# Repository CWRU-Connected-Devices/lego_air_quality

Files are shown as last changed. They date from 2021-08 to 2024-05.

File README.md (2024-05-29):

# Assembly Process

## Wire Preparation
- Cut all wires to length using a piece of cardboard as a reference length
- Stripped and twisted wires    
- Pre-soldered wires 

## Soldering wires to peripherals
- Soldered LEDs
- Soldered Sensors
- Soldered Neopixel LED bars
- Stripped and soldered the fans  

## Peripheral board Assembly
- Soldered male headers onto Peripheral boards
- Soldered peripherals to each Peripheral board
- Cleaned Peripheral boards
- Tested each Peripheral board using a test Pico with female headers soldered on 

## Pico Assembly
- Soldered the rest of the Peripheral boards to Picos
- Flashed using Thonny
- Tested each kit
	- Make sure the LED blinks two times and then lights up    
	- Make sure the Neopixel bar works (will cycle a rainbow pattern)
	- Make sure the calibration process finishes - Neopixel bar turns blue and then turns red
	- Make sure the change in luminance on the sensor results in a corresponding change on the Neopixel bar indicator

## Glueing
- ### LED and Sensor Bricks
	- Hot glue first on brick
	- Place peripheral on layer of glue
	- Finish by covering the rest of peripheral in glue
	- Strain relieved the wires with a drop of hot glue
	- Attached other half of brick by adding superglue to the rim and pressing them together
    
- ### Casing
	- Superglue the bottom to the top of the case
	- Placed Pico/Peripheral board assembly inside case
	- A drop of hot glue under the Pico to hold it in place
	- Final test  
      
## Finishing touches
- Pull the wires through the strain relief bars on the case
- Tie the wires with cable ties

# Uploading code onto pico

1. Hold the BOOTSEL button on the pico and plug it into the computer    
2. Pico folder shows up with two files currently inside
   
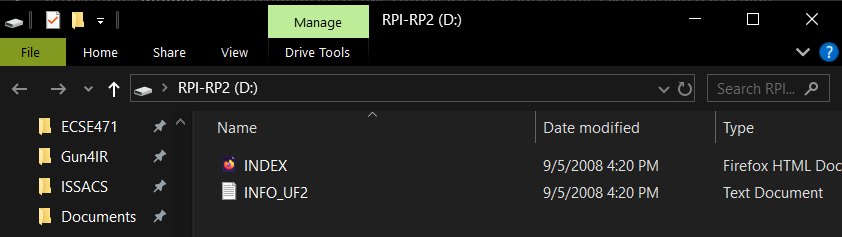
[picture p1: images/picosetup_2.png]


3. Drag the UF2 file into the pico folder
    
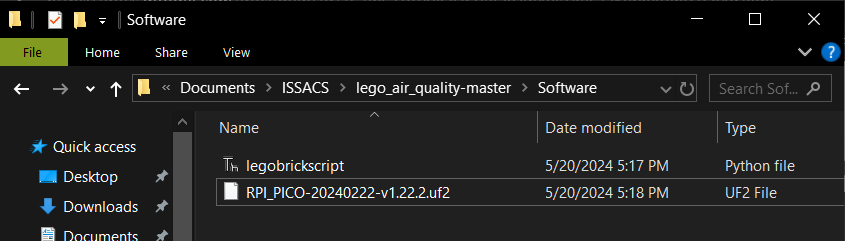
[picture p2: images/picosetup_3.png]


4. Pico folder now closes
5. Open Thonny and at the bottom right corner select the COM port 
   
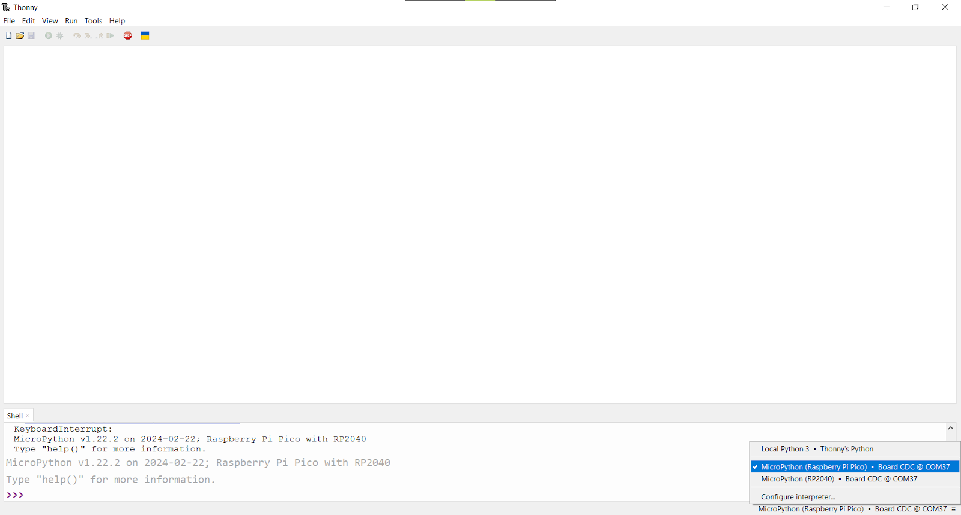
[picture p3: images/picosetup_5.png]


6. Open legobrickscript.py
7. Go to File > Save Copy 
8. When asked where to save, select the Raspberry Pi Pico

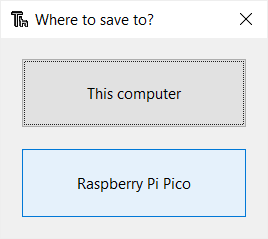
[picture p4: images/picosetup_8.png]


9. Rename the file as main.py and press OK
   
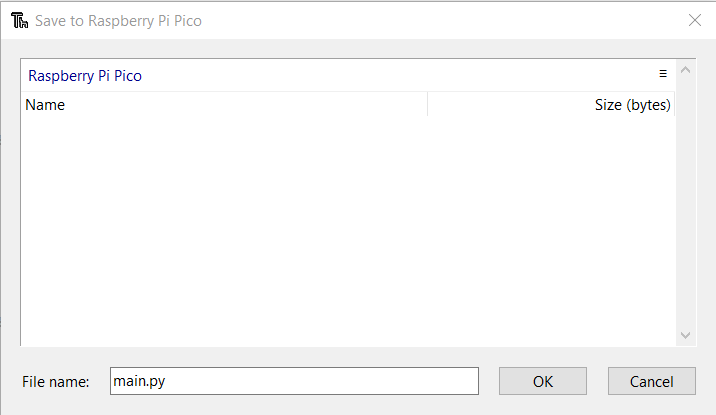
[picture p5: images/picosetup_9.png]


10. Ctrl-D to boot the Pico
    
# Setup

- Used Studio 2.0
   - Download Link https://www.bricklink.com/v3/studio/download.page
    
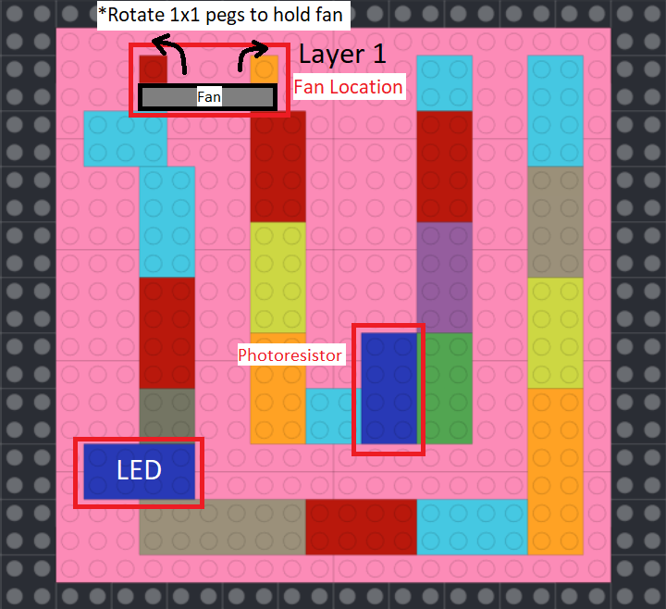
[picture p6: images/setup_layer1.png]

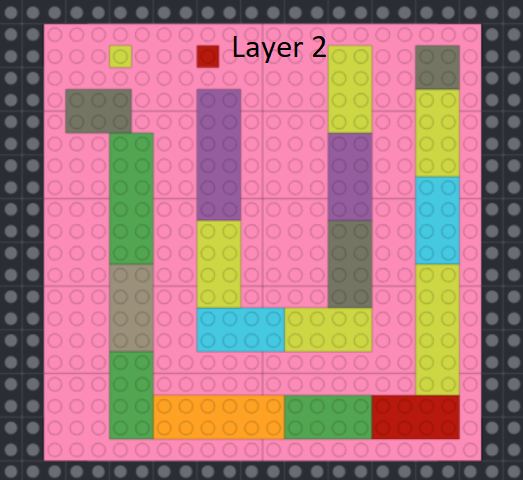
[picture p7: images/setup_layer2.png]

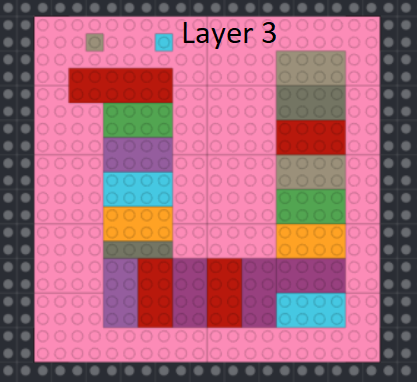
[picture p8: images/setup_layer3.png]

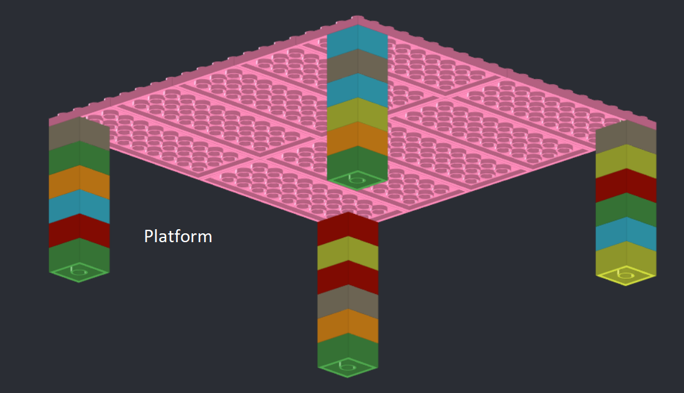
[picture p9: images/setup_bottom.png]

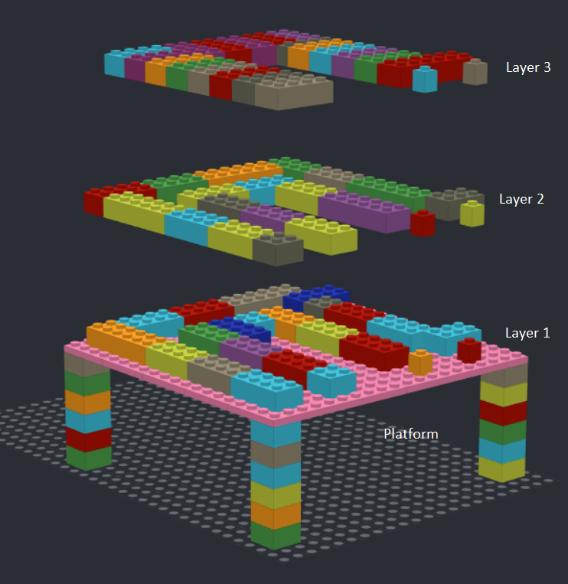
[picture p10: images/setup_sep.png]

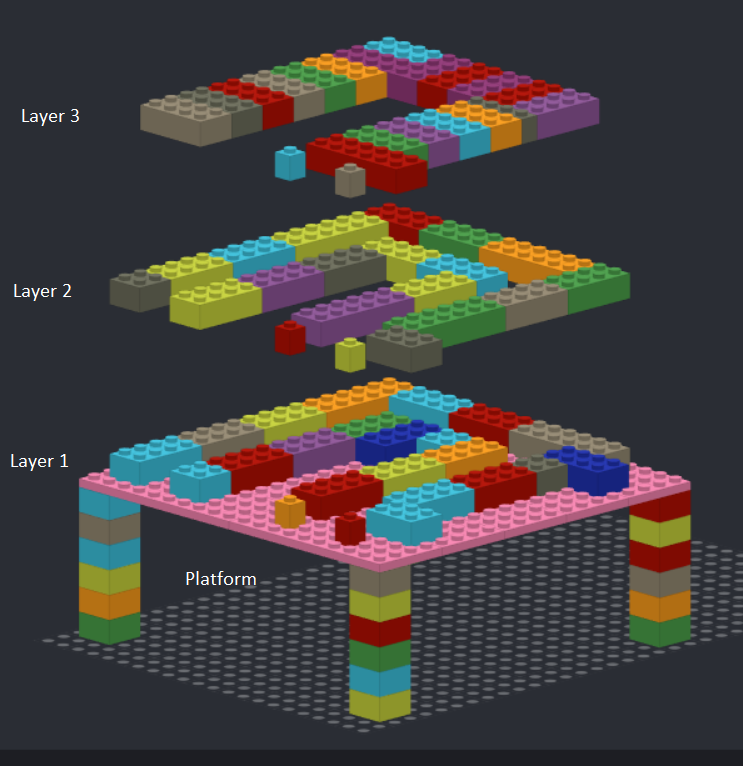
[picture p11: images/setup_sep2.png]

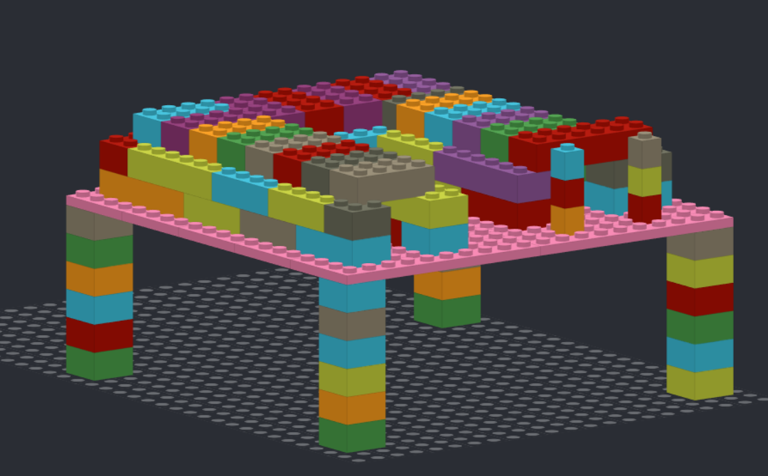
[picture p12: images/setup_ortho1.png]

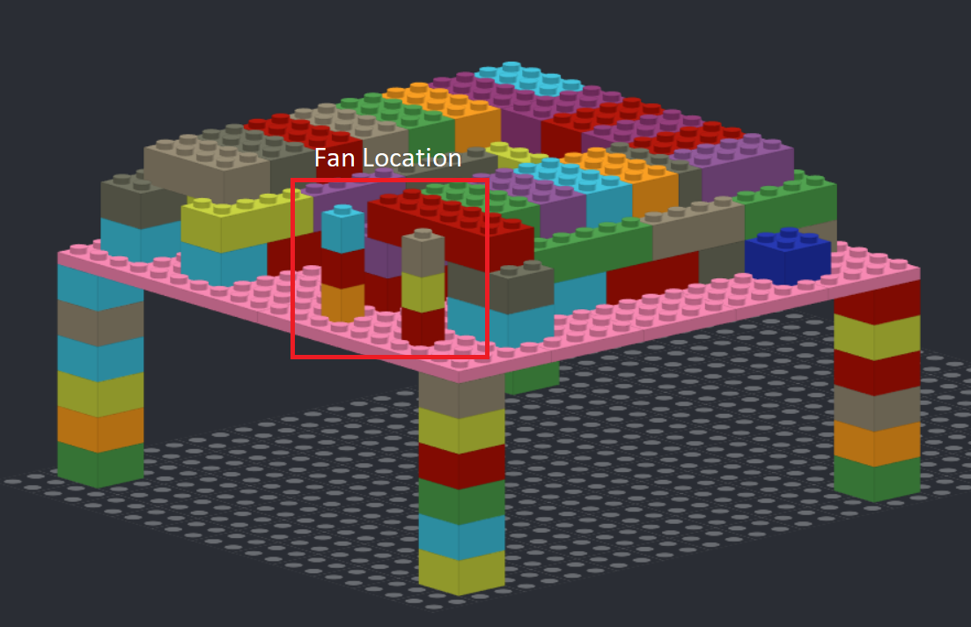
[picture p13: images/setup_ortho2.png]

**

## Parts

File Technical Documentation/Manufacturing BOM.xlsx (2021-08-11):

 | Number of Units | 20
 | Per Kit |  |  |  |  |  | Quantity Needed | Quantity On Hand | Extended
Order Status | Price | Quantity Per Unit | Per Unit Cost | Source | Item Description | Item Link |  |  | Quantity to Order | Price | Notes
finalized | $5.49 | 0.020 | $0.11 | amazon | White LEDs | https://www.amazon.com/gp/product/B004JO2HTA/ref=oh_aui_search_detailpage?ie=UTF8&psc=1 | 0.4 | 59.0 | 0 | $0.00
finalized | $5.69 | 0.020 | $0.11 | amazon | Photoresistors | https://www.amazon.com/dp/B01MSIQRQF/ref=cm_sw_r_cp_ep_dp_UXLuAbJF8D7Y7 | 0.4 | 50.0 | 0 | $0.00
finalized | $0.30 | 1.000 | $0.30 | digikey | 10k ohm resistors | https://www.digikey.com/en/products/detail/stackpole-electronics-inc/RC14JT10K0/1744856 | 20.0 | 0.0 | 20 | $6.01
finalized | $4.00 | 1.000 | $4.00 | canakit | RPi Pico Microcontroller | https://www.canakit.com/raspberry-pi-pico.html?cid=usd&src=raspberrypi | 20.0 | 0.0 | 20 | $80.00
finalized | $9.99 | 0.136 | $1.36 | amazon | 28 gauge wire for sensors | https://www.amazon.com/Electrical-different-Insulated-Temperature-Resistance/dp/B07G2HFCS1 | 2.7 | 0.0 | 3 | $29.97 | 35 inches of wire per kit
finalized | $5.36 | 1.000 | $5.36 | adafruit | Neopixel Strip | https://www.adafruit.com/product/1426 | 20.0 | 0.0 | 20 | $107.20
finalized | $1.95 | 0.150 | $0.29 | digikey | large shrink tubing | https://www.digikey.com/en/products/detail/te-connectivity-raychem-cable-protection/VERSAFIT-3-8-0-SP/6154247 | 3.0 | 0.0 | 3 | $5.85
finalized | $0.95 | 0.250 | $0.24 | digikey | small shrink tubing | https://www.digikey.com/en/products/detail/sumitomo-electric-interconnect-products-inc/A2-1-8-CLEAR-4FT/13170844 | 5.0 | 0.0 | 5 | $4.75
finalized | $22.99 | 0.033 | $0.77 | digikey | PLA Filament | https://www.digikey.com/en/products/detail/polymaker/PM70541/13146620 | 0.7 | 0.0 | 1 | $22.99
finalized | $26.99 | 0.020 | $0.54 | digikey | Solder Paste | https://www.digikey.com/en/products/detail/chip-quik-inc./SMD4300SNL10/2057275 | 0.4 | 0.0 | 1 | $26.99
finalized | $34.99 | 0.042 | $1.46 | amazon | Brick Baseplates | https://www.amazon.com/dp/B01DFOMNAC/ref=cm_sw_su_dp | 0.8 | 0.0 | 1 | $34.99
finalized | $7.50 | 0.060 | $0.45 | amazon | 1x1 bricks | https://www.amazon.com/Lego-Parts-100-Orange-Bricks/dp/B00897JJ58 | 1.2 | 0.0 | 2 | $15.00
finalized | $9.98 | 0.200 | $2.00 | amazon | 5v Fans | https://www.amazon.com/WINSINN-Brushless-Cooling-25x10mm-Notebook/dp/B07KRX9F99 | 4.0 | 0.0 | 4 | $39.92
finalized | $2.50 | 1.000 | $2.50 | amazon | usb hubs | https://www.amazon.com/dp/B07SK6GW33/?coliid=I2C4ICD93FIFAU&colid=1UW3F9YDW5AXN | 20.0 | 0.0 | 20 | $50.00
finalized | $7.99 | 0.333 | $2.66 | amazon | usb cords | https://www.amazon.com/Universal-Rugged-Charger-Android-Samsung/dp/B01NA9UCVQ/ref=sr_1_18?dchild=1 | 6.7 | 0.0 | 7 | $55.93
finalized | $16.70 | 1.000 | $16.70 | amazon | mist generator | https://www.amazon.com/dp/B00GSKCW70/ref=cm_sw_su_dp | 20.0 | 0.0 | 20 | $334.00
finalized | $14.83 | 0.010 | $0.15 | amazon | static proof bags | https://www.amazon.com/Supershield-IC3700-628-ZB-4X6IN-Thickness-Surface-Resistance/dp/B013G49YW6 | 0.2 | 0.0 | 1 | $14.83
finalized | $8.00 | 0.050 | $0.40 | walmart | container for everything | in store at walmart | 1.0 | 0.0 | 1 | $8.00 | unknown price probably just 20 bucks
finalized | $6.25 | 0.125 | $0.78 | target | ziploc containers | https://www.target.com/p/ziploc-twist-39-n-loc-container-8oz/-/A-77378113#lnk=sametab | 2.5 | 1.0 | 2 | $12.50
finalized | $7.99 | 0.500 | $4.00 | amazon | desoldering baseter | https://www.amazon.com/Desoldering-Soldering-Irons-Electronix-Express/dp/B00EO4GN1I | 10.0 | 0.0 | 10 | $79.90
finalized | $6.48 | 0.010 | $0.06 | amazon | super glue | https://www.amazon.com/Gorilla-Super-Glue-Gram-Clear/dp/B00OAAUAX8 | 0.2 | 0.0 | 1 | $6.48
 |  |  |  |  |  | TOTAL |  |  |  | $935.31

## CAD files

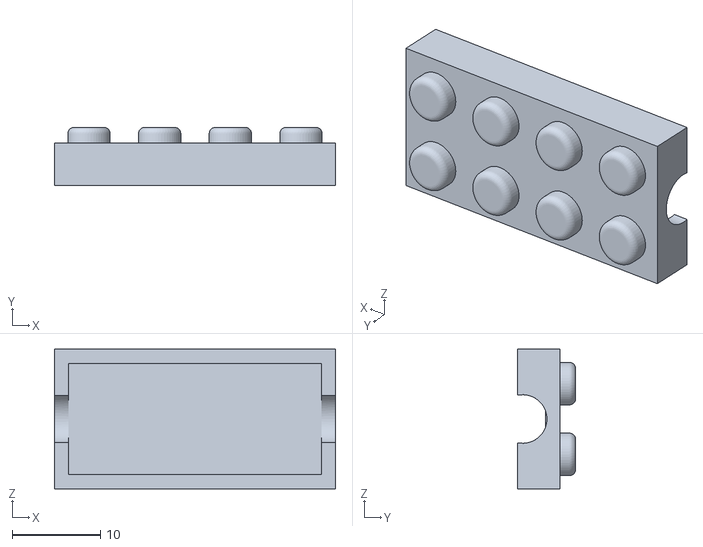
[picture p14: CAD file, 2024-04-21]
Models/V2/lego_top.stl
31.8 x 6.60 x 15.8

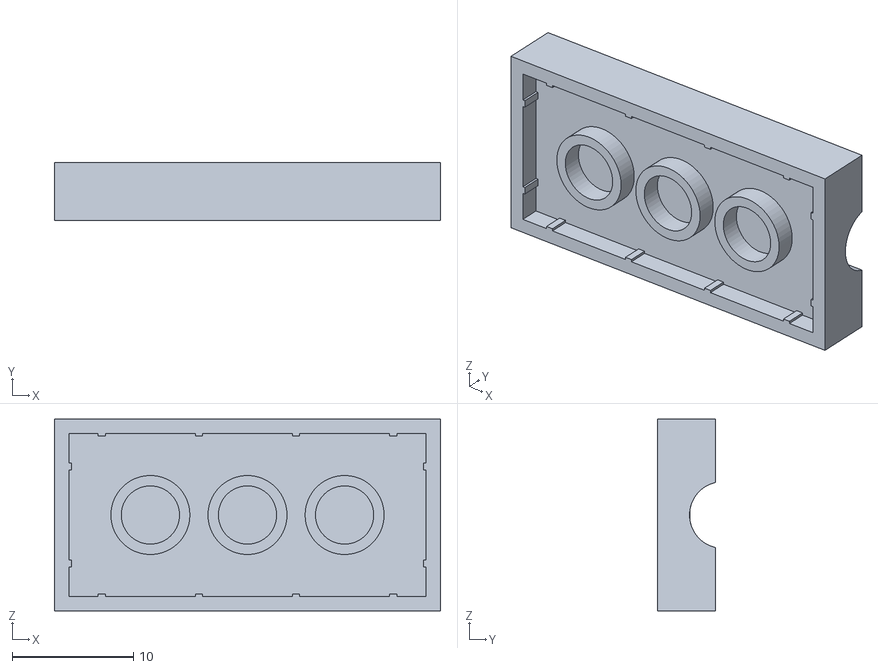
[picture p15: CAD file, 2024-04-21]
Models/V2/lego_bottom.stl
31.8 x 4.80 x 15.8

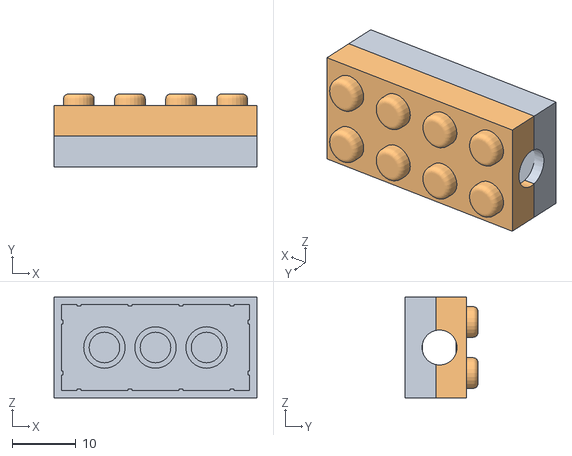
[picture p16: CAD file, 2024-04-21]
Models/V2/2x4 lego brick 3001 v6 v3.obj
31.8 x 11.4 x 15.8
bottom
top

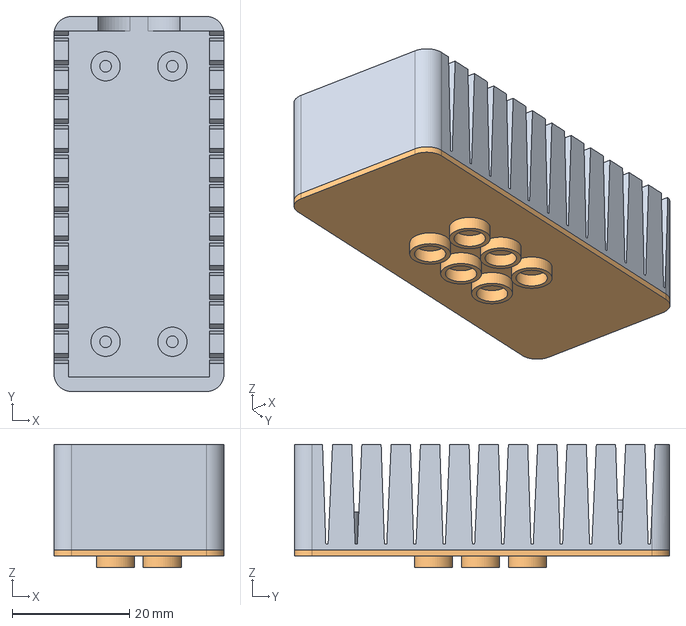
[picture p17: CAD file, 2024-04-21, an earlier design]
Models/V1/Raspberry Pi Pico Case.step
29.0 x 64.0 x 21.0 mm

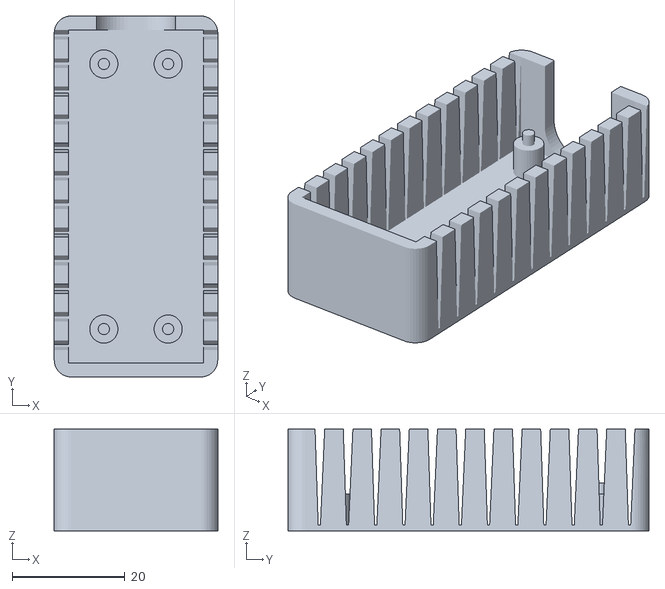
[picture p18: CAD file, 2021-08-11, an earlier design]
Models/V1/Pico Case Top.stl
29.0 x 64.0 x 18.0

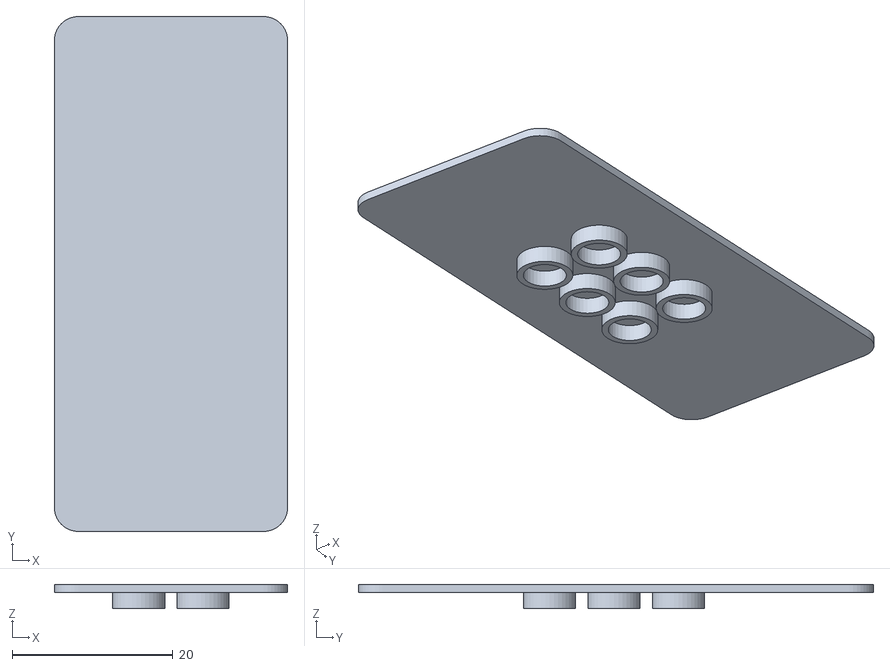
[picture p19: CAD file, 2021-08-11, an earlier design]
Models/V1/Pico Case Bottom.stl
29.0 x 64.0 x 3.00

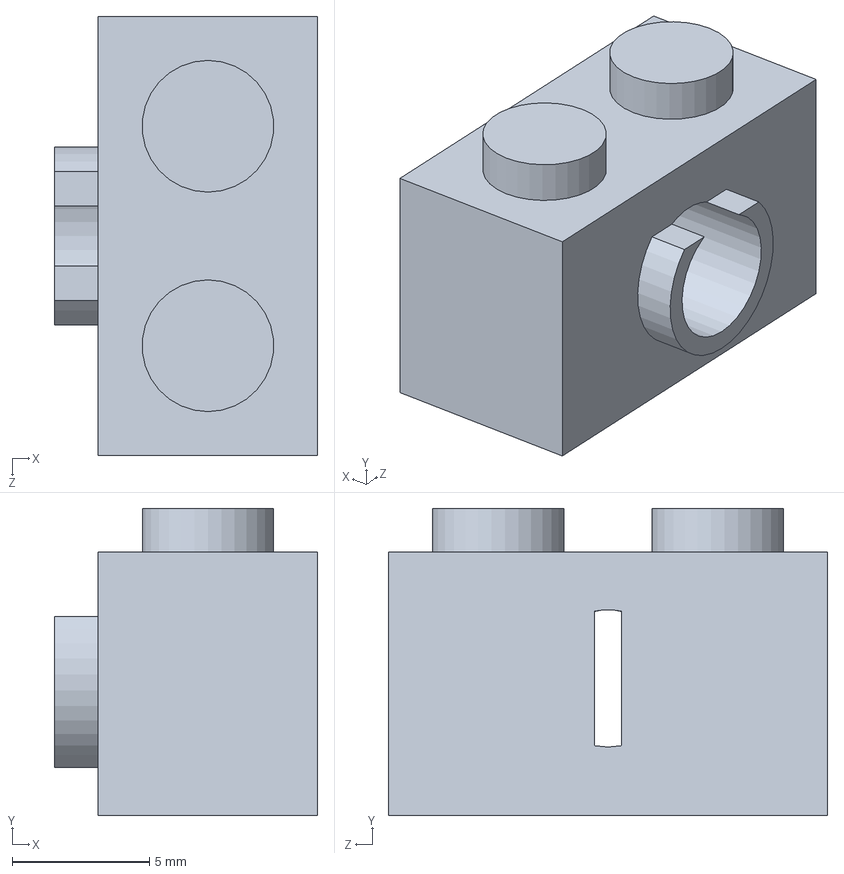
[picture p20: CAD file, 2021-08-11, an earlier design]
Models/V1/LegoLED.SLDPRT
9.60 x 11.2 x 16.0 mm

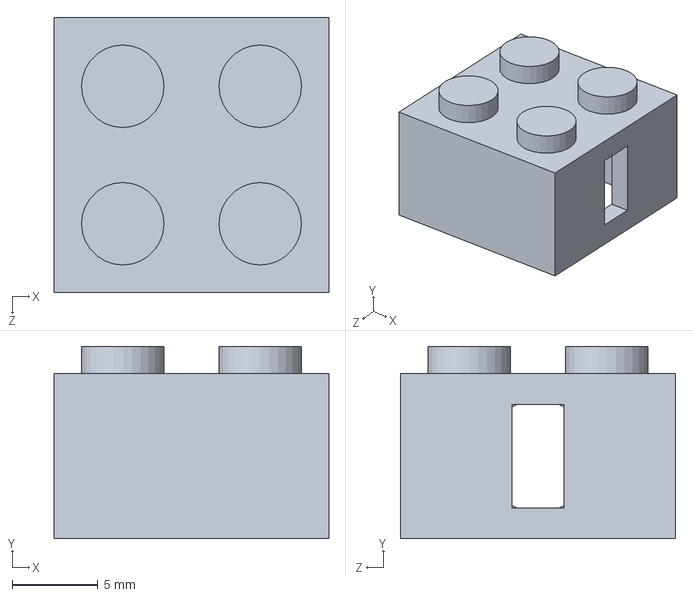
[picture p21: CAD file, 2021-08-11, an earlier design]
Models/V1/WireHousingBrick.SLDPRT
16.0 x 11.2 x 16.0 mm

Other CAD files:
Models/V1/LegoLED.STL
Models/V1/wire-housing-brick.stl
Models/V2/2x4 lego brick 3001 v6 v3.f3d

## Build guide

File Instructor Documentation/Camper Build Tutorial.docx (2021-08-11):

1) Build your enclosure, following the following picture as a guide:

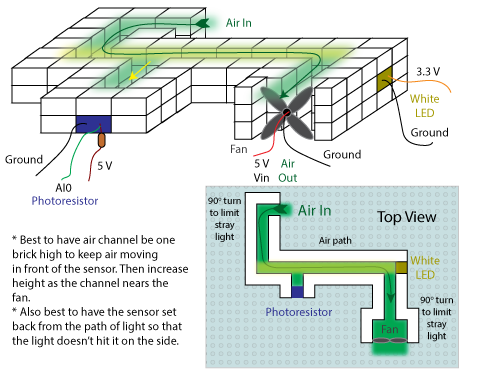
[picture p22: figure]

2) For the fan, I found the below setup to work best. MAKE SURE that air is being pushed into the system and not pulled. There are too many cracks in the legos and holes in the system to get enough suction out the other end if the air is pulled through the system.

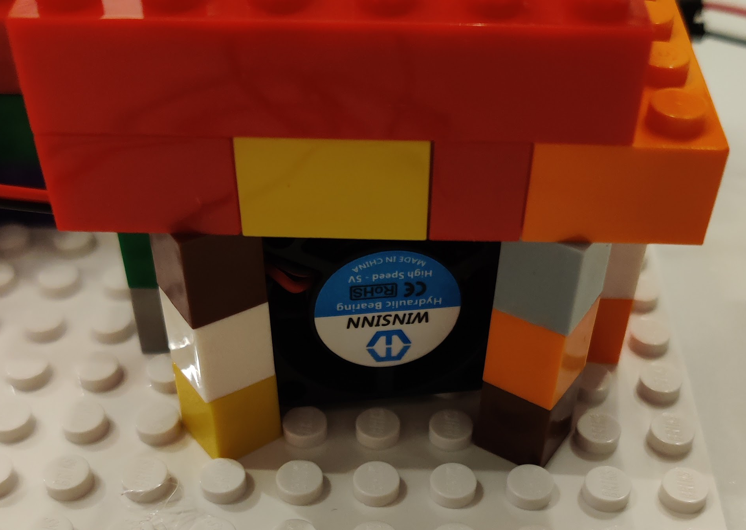
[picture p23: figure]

3) Plug in the micro-usb cord into the microcontroller, and the USB end in the wall socket.
4) The neopixel display will follow the below sequence:
  a) First, the lights will perform a rainbow animation to indicate that power is properly applied to the system. This lasts ~1 second.
  b) Next, the machine will go through a calibration cycle. The lights will first turn yellow and then cyan. If at any point in the calibration cycle the microcontroller detects an error, the lights will turn purple and flash for five cycles.
  c) Next, the strip will become solid yellow. This is the first calibration stage. If an error is detected, the lights will change to purple. To troubleshoot the errors, see the troubleshooting documentation (https://docs.google.com/spreadsheets/d/169syWACnSGSg9ZBuyg8gWDcjOiGvT76oc5x60QT0W34/edit?usp=sharing).
  d) If the microcontroller successfully calibrates, the lights will switch to either being red or off. This is the measurement stage, and the number of lights represents the relative air quality. The microcontroller is programmed to display a measurement relative to what it remembers since turned on. Therefore, the initial measurements will seem really weird, like a clean air rating of 6/8 lights. Once you expose the microcontroller to polluted air values, the microcontroller will have a better understanding of what “polluted air” looks like, and will adjust the display accordingly.

** for steps A-C, make sure that no particulate matter is flowing through the system. If the system is calibrated incorrectly, it will not read the correct relative air pollution.

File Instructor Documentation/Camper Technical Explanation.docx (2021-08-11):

# Calibration and Measurement

When the microcontroller is going through the calibration phase, a couple of pre-coded checks are put in place to ensure that the bricks were assembled in a way that will allow the sensor to succeed.

Rainbow Phase

First, the microcontroller begins with a quick rainbow animation to show that the microcontroller has turned on!

Yellow Phase

Next, the microcontroller reads the light sensor value before and after turning the white LED on. If the two measured values are the same, the purple error lights are shown to tell the builder that there might be an issue with their design!

Cyan Phase

If the yellow phase succeeds, the microcontroller will turn the LED brick on, and read a bunch of sensor readings over two seconds. The microcontroller will remember the largest and smallest values recorded, which will be used in the next phase.

Red Phase

When the cyan phase succeeds, the microcontroller will begin frequently reading the light sensor, and determining an air pollution value. The air pollution sensor works as follows:

1) First, read the light sensor
2) If the light sensor detects a new minimum or maximum light sensor value, it will be remembered for later.
3) Next, the microcontroller will take the region of numbers between the minimum remembered value and maximum remembered value, and divide it into eight different sections, one for each LED on the display brick. Depending on the region that the current measurement falls into, the corresponding amount of red LEDs on the display will light up!
4) This will loop back to step 1) and repeat forever.

This four-step process also explains why at the beginning right after calibration, the air quality will be measured much higher than normal. The microcontroller has no other measurements to compare to, so the eight divided regions are very small. Extremely small changes in the light sensor reading are enough to change the eight red LED measurements. But, when you introduce the particulate matter, a new maximum is introduced to the microcontroller, and the sensor becomes more accurate.

# Individual Component Overview

Work in progress, to be completed 8/11.

Microcontroller Overview

So the “brains of the air quality sensor is a microcontroller, a very small and programmable computer! The microcontroller we are using is called the Raspberry Pi Pico, which is only 4 USD and programmable in a computer science language called Python. The Raspberry Pi Pico has 40 pins that you can turn on or off. To these pins, you can connect wires and control sensors, lights, and many other components.

White LED Brick Overview

The white brick uses a white LED that produces white light when connected to the microcontroller. The bricks were custom designed in a Computer-Aided Design (CAD) software called Solidworks and printed on a 3D Printer. 3D printers melt plastic and draw 2d pictures of plastic on top of each other to create a 3D shape.

Sensor Brick Overview

The teal sensor brick uses a photoresistor to detect light. A photoresistor is an electrical component that will change how much it wants to resist the flow of electricity based on the amount of light shining on its surface. Similar to the white LED, the teal bricks were designed in Solidworks and 3D printed.

Display Lights Overview

The long, 6x1 brick holds a printed circuit board with 8 Neopixels on it. A Neopixel is an RGB LED, which has one red, one green, and one blue led inside of the larger package. Neopixels are special in that you can control specifically the color of each individual light, all from three wires!

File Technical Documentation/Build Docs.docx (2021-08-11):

# White led bricks

1. Print out bricks
2. Cut two wires approx 10 inches long with ¼ inch stripped and exposed wire on one side
3. Put white led into the brick with the cathode (long lead) on top
  a. Make sure to have the “bubble” of the LED protruding from the side of the lego with the small vertical slit, not the hole. The hole is used for hot glue and anchoring the LED in place.
4. Hot glue the LED in place, filling the divot in the brick
5. Bend the leads of the led in prep for wire soldering

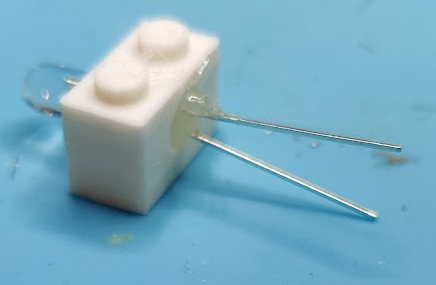
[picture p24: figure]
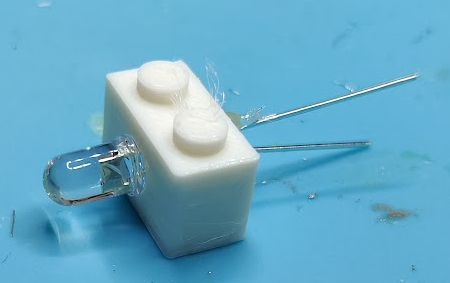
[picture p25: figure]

6. Solder each wire to the LED
  a. I used red for cathode and black for anode
7. Cut approx. quarter-inch of 1/8th inch shrink wrap to fit the sensor
8. Push shrink wrap up the wires so they touch the brick
9. Shrink the wrap with a heat gun
10. Cut ¼ inch of ⅜ inch shrink wrap, and fit the wrap over all wires of led. This protects the wires from bending at an awkward angle.
11. Treat with heat gun to shrink.

# Teal Sensor Bricks

1. Print out bricks
2. Cut three wires approximately 10 inches long with ¼ inch stripped and exposed wire on one side
3. Put photoresistor into the brick on the side with the small vertical slit, not the hole. The hole is used for hot glue.
4. Push leads of the photoresistor to opposite sides of hot glue hole, fill with hot glue
5. Bend leads of the photoresistor to prep for soldering resistor and wire.

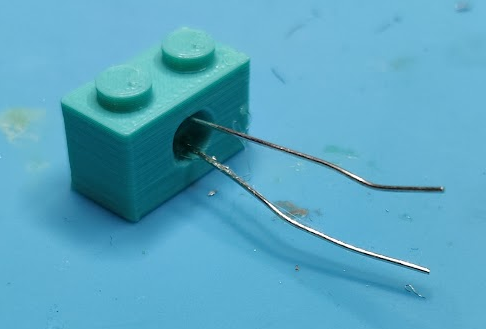
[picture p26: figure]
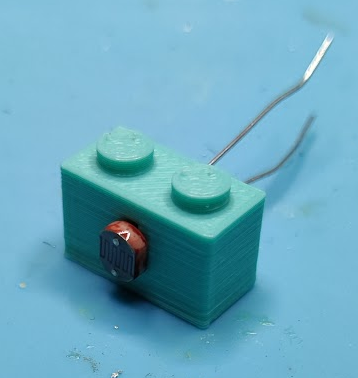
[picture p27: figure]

6. The bottom lead will act as ground to the voltage divider, so solder that one first. I used blue to represent the sensor ground.
7. The top lead will need the 10k ohm resistor and a wire to measure the divided voltage soldered to it. Bend and cut both before hooking them all together and soldering the three-wire/component joint. Yellow wire was used for the signal wire for the voltage divider in the sensor
8. Finally, solder the +3.3v wire to the other end of the resistor. White was used for the 3.3v wire.
9. Prepare shrink wrap:
  a. 1/8th inch long of 1/8th inch diameter
  b. 1/4th inch long of 1/8th inch diameter
  c. 1/2th inch long of 4mm inch diameter
  d. 1/2th inch long of 3/8th inch diameter
10. Use shrink wrap a) to cover the joint between the white wire and resistor
11. Use shrink wrap b) to cover the joint between photoresistor and blue wire
12. Use shrink wrap c) to cover the joint between the photoresistor, resistor, and the signal (yellow) wire. Make sure to feed the shrink wrap through both the white and yellow wire.
13. Once a-c has been shrunk, combine all three wires and two components together with shrink wrap d).

# Neopixel Assembly

1. Cut and strip three wires to ten inches long with ¼ inch exposed wire on one side.
2. Place the neopixel strip on a heat-proof surface with the solder pads facing up.
3. Tape the neopixel strip down with duct tape/electrical tape’
4. Apply solder paste to the solder pads
5. Align wires with solder pads, and apply solder. Try to minimize exposed wire hanging out of the board, as it would be a point of weakness.

# Full Board Assembly

1. For each wired brick, pull the wires and cut any excess length to ensure all wires are the same length. Strip each wire so they have the same length of exposed wire (approx. ¼ inch)
2. Use helping hands to arrange the neopixel board stationary with extra hands to help with wires.
3. Begin with the neopixel brick, soldering it into the RPi Pico board following the wiring guide spreadsheet. Make sure wires are going into the side of the Pico board with the processor. Having the processor facing up allows for a clean connection on the printed lego-adaptor. Additionally, it is nice for the students to see the components of the chip easily.
4. Once neopixel is assembled, it is highly recommended to test the RPi Pico board following the testing document to ensure that the board works before continuing.
5. If the board is working properly, continue to solder the two sensor bricks and fan module in accordance to the wiring spreadsheet.
6. Proceed to full-board testing at the bottom of the testing document.

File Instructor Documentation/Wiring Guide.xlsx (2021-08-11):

 | Output
VBUS | Fan +5v
VSYS | NEOPIXEL +5v
GPIO15 | White LED +5v
3V3 | Sensor +3.3v
GPIO22 | NEOPIXEL DIN
GPIO26 | Sensor Data
GND | NEOPIXEL GND
GND | White LED GND
GND | Fan GND
GND

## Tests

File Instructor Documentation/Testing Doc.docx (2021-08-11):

# White LED Brick Testing

1. A variable power supply was set to 3.3v and hooked up to each LED to test functionality.
2. Each led drew ~ 0.02-0.03 amps of current and would light up brightly.

# Teal Sensor Brick Testing

1. Use a power supply to apply +3.3v to the 3.3v white wire and connect the ground of the power supply to the blue ground wire.
2. Use a multimeter connected to power supply ground, and the other lead connected to the signal wire (yellow) of the sensor. Measure the resistance in light and out of light.
3. Make sure the voltage from signal pin is high in the light and low in the dark. It’s not the end of the world if it is backwards - you can just reverse the +3.3v and GND wires.
  a. For my environment, in the dim light from a couple overhead lights in my basement, the resting voltage is around 2v to 2.3v.

# Neopixel Brick Testing

1. An additional RPi Pico was set up running the normal script. Temporary alligator clips connected the +5v, GND, and DIN pin of the neopixel strip to the corresponding pins in the microcontroller (shown in wiring guide spreadsheet)
2. Plug in the usb to a power supply or computer, run the script
3. You should see the rainbow animation occur, indicating that the microcontroller is starting up.
4. If so, neopixel brick is working.

# Fan Testing

1. Set power supply to 5v
2. Connect exposed wires of fan to 5v and gnd
3. If fan works, it should be blowing air.

# RPi Pico Board Testing

1. After soldering the neopixel brick onto the pico, plug in the pico to power to ensure that the neopixel strip lights up accordingly. It is safe to use neopixel strips in testing the Pico because they were confirmed to work in the neoopixel brick testing section.
2. If the neopixel strip works, proceed and solder the rest of the board up.

# RPi Pico Board Testing After Completion

1. Construct a demo lego enclosure that can easily be used to plug in each lego sensor
2. For each wire harness, plug in each sensor, fan and led and ensure that the water sensor works.

# Mist generator testing

1. After full construction of mist generator, plug in to a wall to ensure that the mist generator works.

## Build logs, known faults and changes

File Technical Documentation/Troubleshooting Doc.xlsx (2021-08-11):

Symptom | Steps to fix (Day Of) | Cause | Steps to Fix (Long Term)
Display stops working | get a new unit from the extras bag. If no extras, "hail mary" fix could be checking the pins on the microcontroller to see if there are any small wires or conductive material bridging the gap between 2 soldered pins. | Wire becomes disconnected from unit/short circuit on the board | check if overlapping small wires on board. if not, resolder new display.
White LED stops working | get a new unit from the extras bag. If no extras, "hail mary" fix could be checking the pins on the microcontroller to see if there are any small wires or conductive material bridging the gap between 2 soldered pins. | Wire has been disconnected form unit/short circuit on the board | check if overlapping small wires on board. if not, resolder new LED.
Fan stops blowing | get a new unit from the extras bag. If no extras, "hail mary" fix could be checking the pins on the microcontroller to see if there are any small wires or conductive material bridging the gap between 2 soldered pins. | Wire has been disconencted from the unit/short circuit on board/internal fan error | check if overlapping small wires on board. if not, resolder new fan.
Nothing happens when you plug in the wall power | try unpluging and plugging back in. If failure, get new unit from extras bag. | internal microcontroller board failure | replace microcontroller
Water spills on the microcontroller | Unplug the microcontroller and get a new unit from the extras bag. | water damage | let dry and try again when dry. if still malfunctioning, replace microcontroller.
purple display light flashes (brick assembly issue) | Make sure the camper's light sensor is not exposed to outside light, and is faced 90 degrees from the white led down the path. | poor brick assembly is leading to light sensor reading similar values when white LED is on and off | diagnose problem more with USB connection to computer. potentially replace sensor
purple LED flashes (hardware issue) | If the purple LED is flashing but the camper's brick setup is correct, a hardware issue may be invovled. get a new unit from the extras bag. | Disconnected wire/short circuit on sensor | diagnose problem more with USB connection to computer. potentially replace sensor

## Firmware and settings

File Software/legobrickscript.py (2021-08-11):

# Example using PIO to drive a set of WS2812 LEDs.

import array, utime
from machine import Pin, ADC
import rp2
from ucollections import deque
#################### CONSTANTS ########################
# Configure the number of WS2812 LEDs.
NUM_LEDS = 8
PIN_NUM = 22
brightness = 0.2
AVGNUM = 100

################### VARIABLES #########################

#PINS
white_led = Pin(15, Pin.OUT)
sensor_in = ADC(26)

#MEASUREMENT
senval = 0
mean_sens = 0
min_sens = -1
max_sens = 0
percent = 0
nlights = 0

#FILTERING
dt = 0
t = 0
iavg = 0
avgsum = 0
filtsenval = 0

alpha = 10
tau = 200

#rolling average
NUM_MEASUREMENTS = 20
filtsenvals_list = deque((), NUM_MEASUREMENTS+1)
roll_sum = 0
rolled_avg = 0


@rp2.asm_pio(sideset_init=rp2.PIO.OUT_LOW, out_shiftdir=rp2.PIO.SHIFT_LEFT, autopull=True, pull_thresh=24)
def ws2812():
    T1 = 2
    T2 = 5
    T3 = 3
    wrap_target()
    label("bitloop")
    out(x, 1)               .side(0)    [T3 - 1]
    jmp(not_x, "do_zero")   .side(1)    [T1 - 1]
    jmp("bitloop")          .side(1)    [T2 - 1]
    label("do_zero")
    nop()                   .side(0)    [T2 - 1]
    wrap()


# Create the StateMachine with the ws2812 program, outputting on pin
sm = rp2.StateMachine(0, ws2812, freq=8_000_000, sideset_base=Pin(PIN_NUM))

# Start the StateMachine, it will wait for data on its FIFO.
sm.active(1)

# Display a pattern on the LEDs via an array of LED RGB values.
ar = array.array("I", [0 for _ in range(NUM_LEDS)])

##########################################################################
def pixels_show():
    dimmer_ar = array.array("I", [0 for _ in range(NUM_LEDS)])
    for i,c in enumerate(ar):
        r = int(((c >> 8) & 0xFF) * brightness)
        g = int(((c >> 16) & 0xFF) * brightness)
        b = int((c & 0xFF) * brightness)
        dimmer_ar[i] = (g<<16) + (r<<8) + b
    sm.put(dimmer_ar, 8)
    utime.sleep_ms(10)

def pixels_set(i, color):
    ar[i] = (color[1]<<16) + (color[0]<<8) + color[2]

def pixels_fill(color):
    for i in range(len(ar)):
        pixels_set(i, color)

def pixels_fill_partial(count, color):
    for i in range(count):
        pixels_set(i, color)
    for i in range(count, len(ar)):
        pixels_set(i, BLACK)
    pixels_show()    

def color_chase(color, wait):
    for i in range(NUM_LEDS):
        pixels_set(i, color)
        utime.sleep(wait)
        pixels_show()
    utime.sleep(0.2)

def wheel(pos):
    # Input a value 0 to 255 to get a color value.
    # The colours are a transition r - g - b - back to r.
    if pos < 0 or pos > 255:
        return (0, 0, 0)
    if pos < 85:
        return (255 - pos * 3, pos * 3, 0)
    if pos < 170:
        pos -= 85
        return (0, 255 - pos * 3, pos * 3)
    pos -= 170
    return (pos * 3, 0, 255 - pos * 3)


def rainbow_cycle(wait):
    for j in range(255):
        for i in range(NUM_LEDS):
            rc_index = (i * 256 // NUM_LEDS) + j
            pixels_set(i, wheel(rc_index & 255))
        pixels_show()
        utime.sleep(wait)

BLACK = (0, 0, 0)
RED = (255, 0, 0)
YELLOW = (255, 150, 0)
GREEN = (0, 255, 0)
CYAN = (0, 255, 255)
BLUE = (0, 0, 255)
PURPLE = (180, 0, 255)
WHITE = (255, 255, 255)
COLORS = (BLACK, RED, YELLOW, GREEN, CYAN, BLUE, PURPLE, WHITE)

# print("fills")
# for color in COLORS:
#     pixels_fill(color)
#     pixels_show()
#     time.sleep(0.2)
# 
# print("chases")
# for color in COLORS:
#     color_chase(color, 0.01)
# 
# print("rainbow")
# rainbow_cycle(0)
#

def raise_error():
    for x in range(5):
        print('error detected!')
        color_chase(PURPLE, 0.1)
        color_chase(BLACK, 0.1)
        
def init_sensor_unit():
    print('initializing sensor...')
    low_values = []
    high_values = []
    for x in range(3):
    
        white_led.value(0)
        utime.sleep(0.5)
        low_values.append(sensor_in.read_u16())
        white_led.value(1)
        utime.sleep(0.5)
        high_values.append(sensor_in.read_u16())
    print(low_values, high_values)
    #test to see if bad sensor plugs
    for x,y in zip(low_values, high_values):
        if abs(y - x) < 1500:
            raise_error()
            break

def read_baseline():
    global mean_sens
    global senval
    global min_sens
    global max_sens
    
    start_time = utime.ticks_ms()
    counter = 0
    while (utime.ticks_ms() - start_time) < 3000:
        counter += 1
        senval = sensor_in.read_u16()
        mean_sens = (mean_sens * counter + senval)/(counter + 1)
        
        
        if min_sens > senval or min_sens == -1:
            min_sens = senval
        if max_sens < senval:
            max_sens = senval
            
        utime.sleep_ms(50)
        print("calibrating mean:", mean_sens, "current min:", min_sens, "current max:", max_sens)
        current_time = utime.ticks_ms()
    
    range_sens = max_sens - min_sens
    min_sens = mean_sens
    max_sens = mean_sens + range_sens

rainbow_cycle(0)
color_chase(BLACK, 0.1)

#visuals to show if sensor unit is working correctly
color_chase(YELLOW, 0.1)
init_sensor_unit()
color_chase(BLACK, 0.1)

#turn on led
white_led.value(1)

# establish a generic min/max
color_chase(CYAN, 0.1)
read_baseline()
color_chase(BLACK, 0.1)


#main loop of program
while True:
    utime.sleep(0.1)
    dt = utime.ticks_ms() - t
    print(dt)
    t = utime.ticks_ms()
    
    #####   FILTERING    #####
    alpha = dt/(tau + dt)
    senval = sensor_in.read_u16()
    filtsenval = filtsenval + alpha * (senval-filtsenval)
    print('alpha:', alpha, 'senval', senval, 'filtsenval', filtsenval)
    
    if max_sens < filtsenval:
        print("new max found...")
        max_sens = filtsenval

    ####    ROLLED AVERAGE    ####
    filtsenvals_list.append(filtsenval)
    
    roll_sum += filtsenval
    if len(filtsenvals_list) == NUM_MEASUREMENTS+1:
        roll_sum -= filtsenvals_list.popleft()
    
        
        rolled_avg = roll_sum/NUM_MEASUREMENTS
        
        ####    LIGHT OUTPUT DETERMINATION    ####
        percent = round(100*(rolled_avg - min_sens)/(max_sens - min_sens))
        nlights = round(percent*NUM_LEDS/100)
        
        if nlights < 1:
            print("percent too low, overriding!")
            nlights = 1
            percent = 0
            
        if percent > 100:
            print("GREATER THAN 100, overriding! percent:", percent)
            percent = 100
            nlights = NUM_LEDS
        pixels_fill_partial(nlights, RED)
        print("%: ", percent, "nlights:", nlights, "senval:", senval, "fsenval:", filtsenval, "min:", min_sens, "max:", max_sens)    

    print('len:', len(filtsenvals_list), 'roll sum:', roll_sum, 'roll avg:', rolled_avg)

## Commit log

2024-04-03 Adding files for custom PCB
2024-04-21 added new lego models
    [2x4 lego brick 3001 v6 v3.f3d, 2x4 lego brick 3001 v6 v3.obj, LegoLED.SLDPRT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]
